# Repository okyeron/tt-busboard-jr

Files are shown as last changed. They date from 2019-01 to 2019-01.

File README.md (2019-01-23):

# TT-Busboard-Jr.

A small powered i2c busboard for the monome/teletype i2c ecosystem

This is compact powered i2c busboard suitable for use with Monome Teletype, Trilogy and other i2c modules. 

Provides three i2c / ii headers with pull-ups to support larger i2c / ii networks.

You can connect up to six modules with regular (1x3) i2c jumpers, or more using "flying bus" cables to connect multiple modules in series.

This busboard is designed to just hang out in the back of your rack - rather than be directly attached to a module.

PCBs and full-built versions of this project are available via https://denki-oto.weebly.com
Or just make you own!

## bom

* (3) header, male, 2x3 
* (1) 3v3 voltage regulator AZ1117CH-3.3TRG1DICT-ND
* (2) resistor 0805 2.2k 
* (1) header, male, shrouded, 2x5 

Adapted from the [Teletype Busboard](https://github.com/monome/tt-busboard) by Brian Crabtree (Monome)

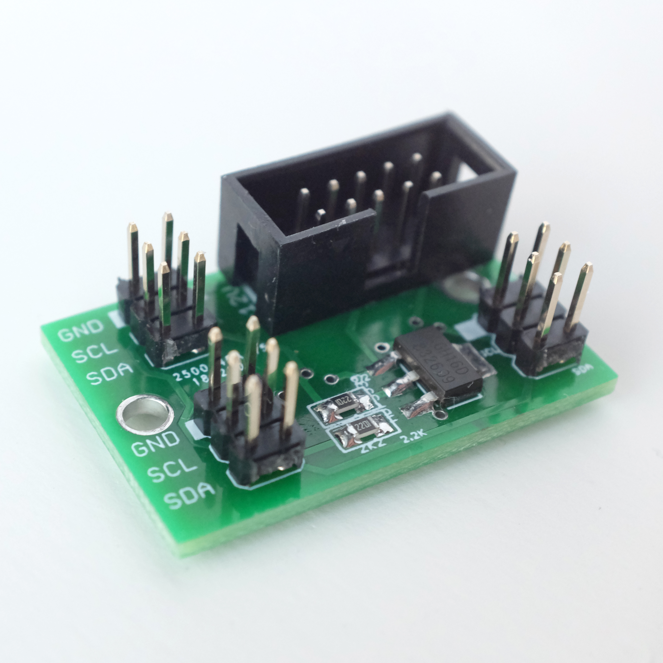
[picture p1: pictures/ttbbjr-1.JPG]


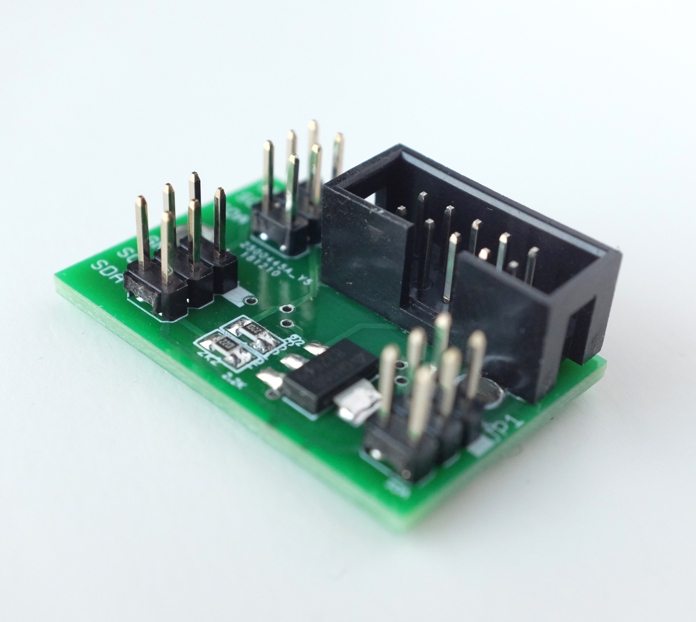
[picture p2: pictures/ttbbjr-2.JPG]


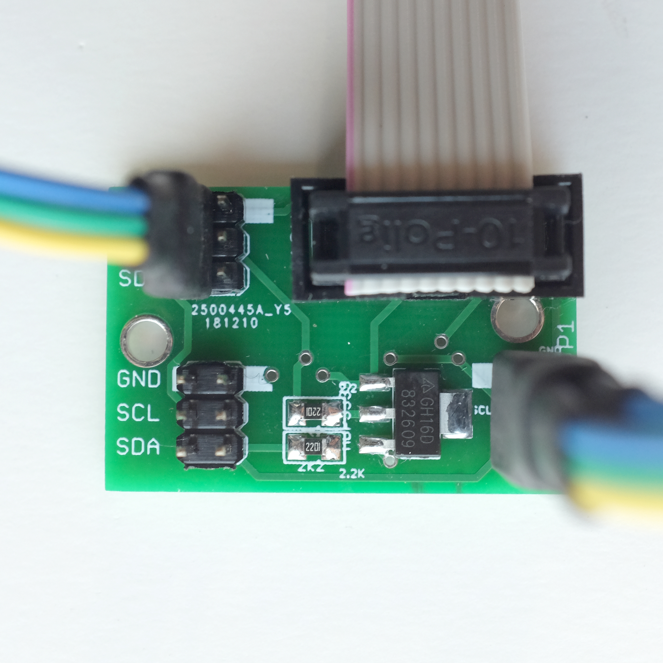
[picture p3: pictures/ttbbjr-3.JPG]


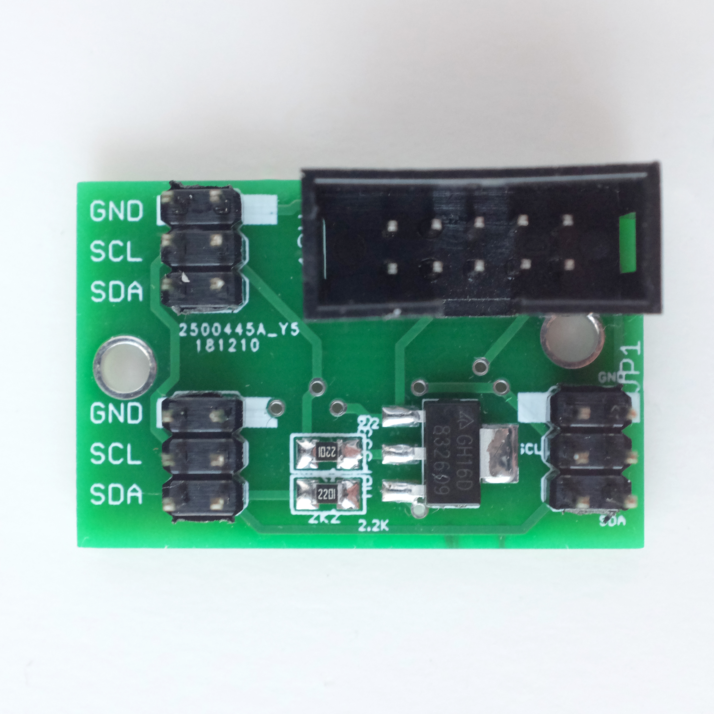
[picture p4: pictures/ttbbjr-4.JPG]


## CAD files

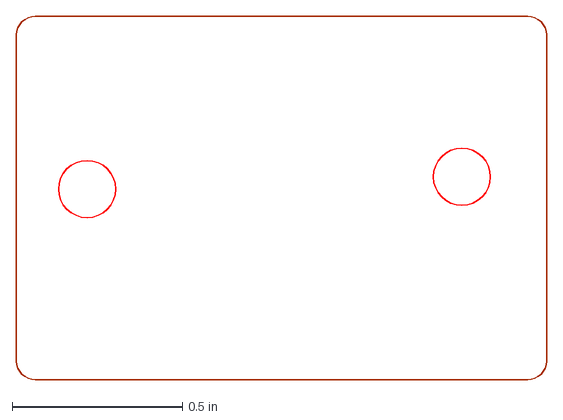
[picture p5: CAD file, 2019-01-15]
back cover/tt-bb-jr_back.dxf
1.56 x 1.07 in

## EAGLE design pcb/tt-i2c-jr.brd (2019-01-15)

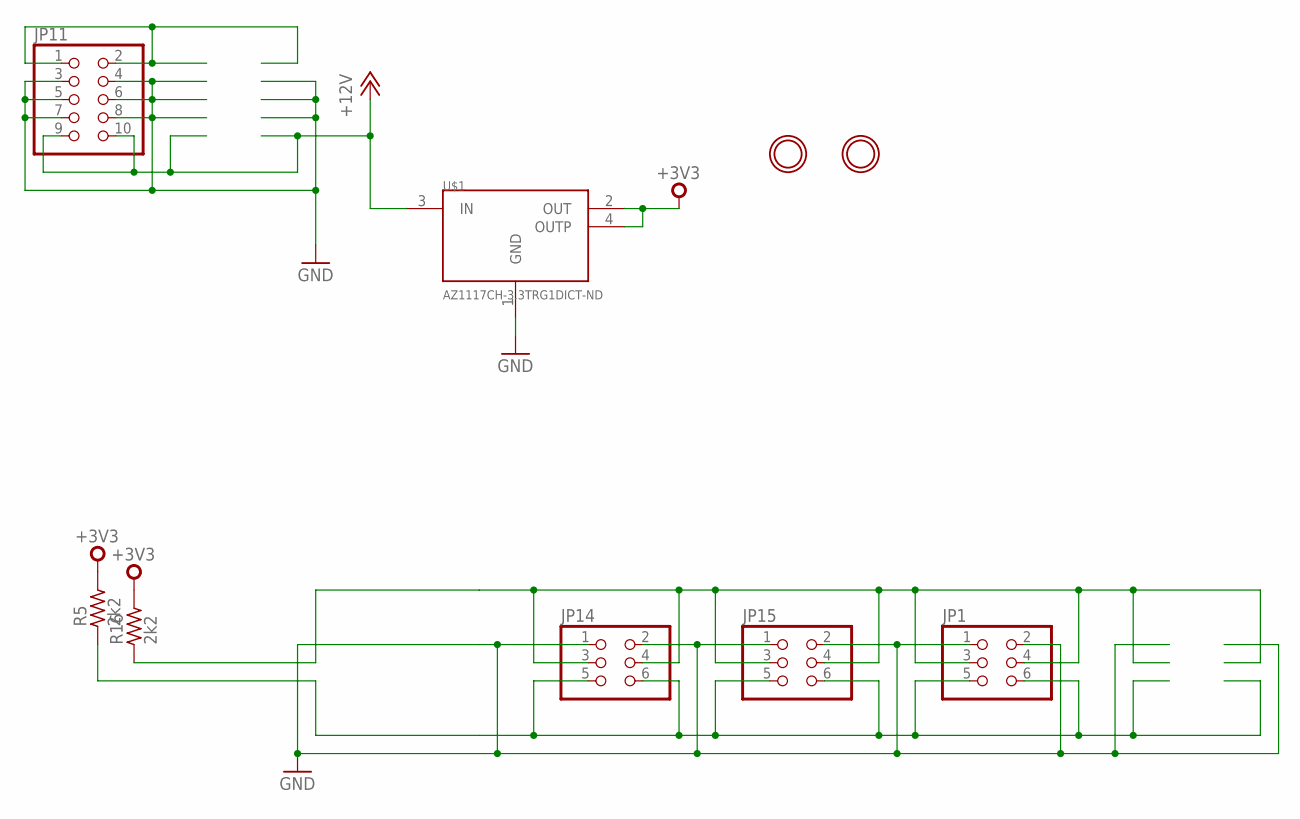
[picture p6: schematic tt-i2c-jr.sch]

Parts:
JP1, JP14, JP15: PINHD-2X3; 2X03
JP11: PINHD-2X5; 2X05
R5, R16: 2k2; R1206
U$1: AZ1117CH-3.3TRG1DICT-ND; SOT223
U$2, U$3: MOUNTINGHOLE3.0THIN; MOUNTINGHOLE_3.0_PLATEDTHIN

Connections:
+3V3: R5.2, R16.2, U$1.2 (OUT), U$1.4 (OUTP)
+12V: JP11.9, JP11.10, U$1.3 (IN)
GND: JP1.1, JP1.2, JP11.3, JP11.4, JP11.5, JP11.6, JP11.7, JP11.8, JP14.1, JP14.2, JP15.1, JP15.2, U$1.1 (GND)
unnamed: JP11.1, JP11.2
SCL: JP1.3, JP1.4, JP14.3, JP14.4, JP15.3, JP15.4, R16.1
SDA: JP1.5, JP1.6, JP14.5, JP14.6, JP15.5, JP15.6, R5.1

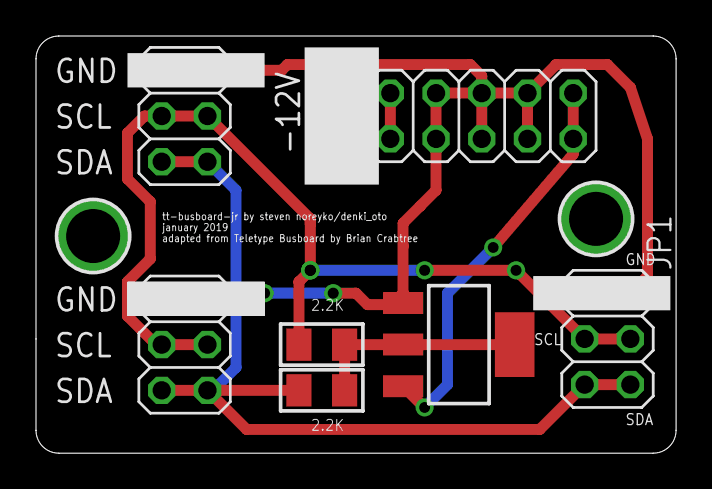
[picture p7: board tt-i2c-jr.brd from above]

Board: 2 copper layers, 35.6 x 23.2 mm, 9 parts (0 on the bottom side), 6 nets.

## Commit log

2019-01-13 add folders
    [tt-i2c-jr.brd, tt-i2c-jr.sch]
2019-01-13 add dxf for back cover
    [tt-bb-jr_back.dxf]
2019-01-15 updated board files/dxf
    [tt-bb-jr_back.dxf, tt-i2c-jr.brd, tt-i2c-jr.sch]
2019-01-16 gerber tweaks

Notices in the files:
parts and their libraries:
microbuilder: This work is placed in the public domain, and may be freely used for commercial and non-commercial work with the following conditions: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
